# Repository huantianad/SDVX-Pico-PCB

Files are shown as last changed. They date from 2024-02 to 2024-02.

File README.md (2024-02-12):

# SDVX Pico PCB

A quick and dirty custom PCB I designed for use with a Raspberry Pi Pico. Wired up for 7 buttons and 2 knobs, and option WS2812B strip. Connectors are JST-XH, with button LEDs running off of 5V. Because of that, I used 2N2222 BJTs to toggle the LEDs off of the 3.3V on the pico.

Indended for use with a slightly tweaked [Pico-Game-Controller](https://github.com/huantianad/Pico-Game-Controller). You may have to edit the encoder PPR and encoder inversion settings.

Encoders are wired for Data, Data, +5V, GND; buttons are wired for Switch GPIO, LED GND, LED 5V, Switch GND.

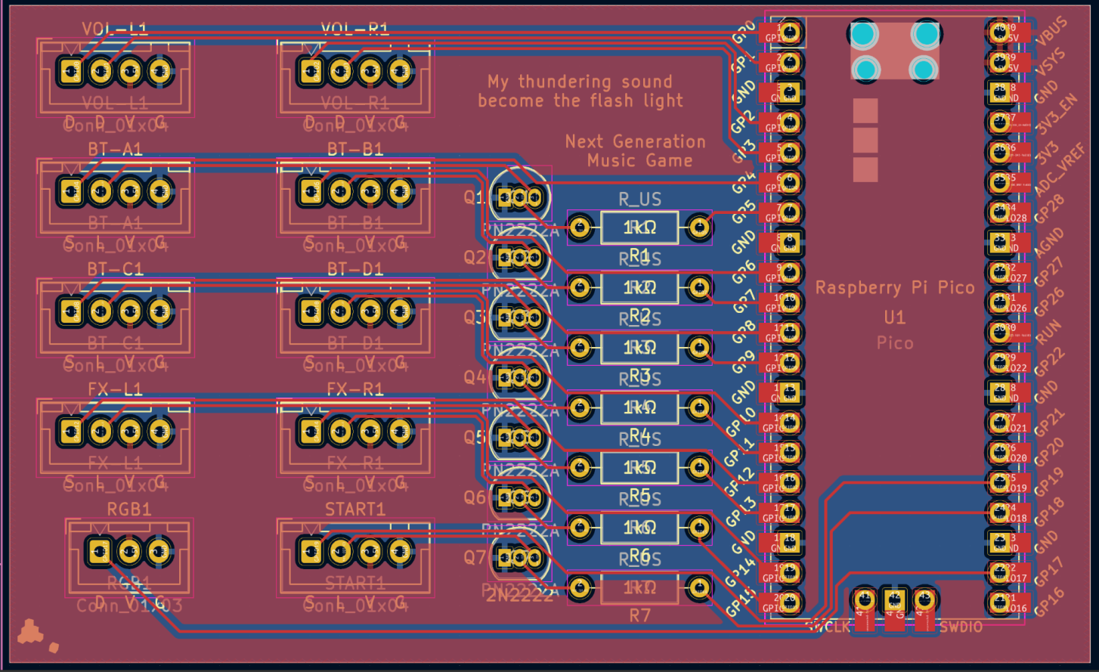
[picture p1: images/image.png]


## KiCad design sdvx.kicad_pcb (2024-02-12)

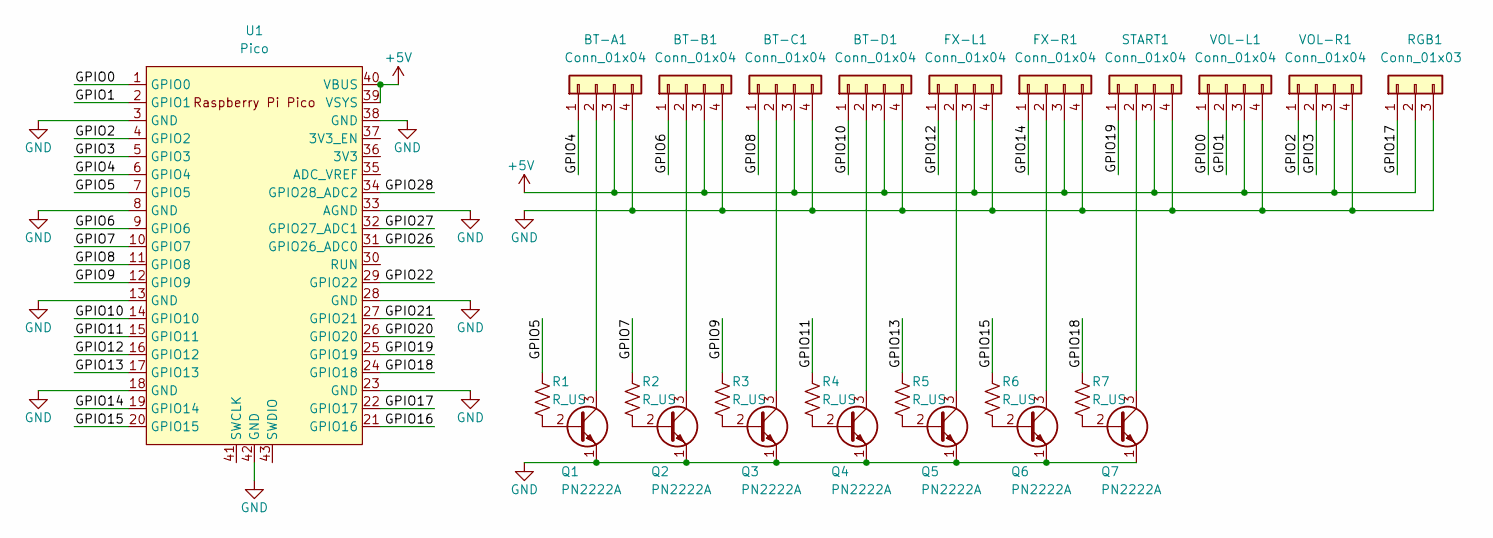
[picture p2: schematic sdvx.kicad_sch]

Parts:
BT-A1: Conn_01x04; JST_XH_B4B-XH-A_1x04_P2.50mm_Vertical
BT-B1: Conn_01x04; JST_XH_B4B-XH-A_1x04_P2.50mm_Vertical
BT-C1: Conn_01x04; JST_XH_B4B-XH-A_1x04_P2.50mm_Vertical
BT-D1: Conn_01x04; JST_XH_B4B-XH-A_1x04_P2.50mm_Vertical
FX-L1: Conn_01x04; JST_XH_B4B-XH-A_1x04_P2.50mm_Vertical
FX-R1: Conn_01x04; JST_XH_B4B-XH-A_1x04_P2.50mm_Vertical
Q1, Q2, Q3, Q4, Q5, Q6, Q7: PN2222A; TO-92_Inline
R1, R2, R3, R4, R5, R6, R7: R_US; R_Axial_DIN0207_L6.3mm_D2.5mm_P10.16mm_Horizontal
RGB1: Conn_01x03; JST_XH_B3B-XH-A_1x03_P2.50mm_Vertical
START1: Conn_01x04; JST_XH_B4B-XH-A_1x04_P2.50mm_Vertical
U1: Pico; RPi_Pico_SMD_TH
VOL-L1: Conn_01x04; JST_XH_B4B-XH-A_1x04_P2.50mm_Vertical
VOL-R1: Conn_01x04; JST_XH_B4B-XH-A_1x04_P2.50mm_Vertical

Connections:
+5V: BT-A1.3, BT-B1.3, BT-C1.3, BT-D1.3, FX-L1.3, FX-R1.3, RGB1.2, START1.3, U1.39 (VSYS), U1.40 (VBUS), VOL-L1.3, VOL-R1.3
/GPIO0: U1.1 (GPIO0), VOL-L1.1
/GPIO1: U1.2 (GPIO1), VOL-L1.2
/GPIO2: U1.4 (GPIO2), VOL-R1.1
/GPIO3: U1.5 (GPIO3), VOL-R1.2
/GPIO4: BT-A1.1, U1.6 (GPIO4)
/GPIO5: R1.1, U1.7 (GPIO5)
/GPIO6: BT-B1.1, U1.9 (GPIO6)
/GPIO7: R2.1, U1.10 (GPIO7)
/GPIO8: BT-C1.1, U1.11 (GPIO8)
/GPIO9: R3.1, U1.12 (GPIO9)
/GPIO10: BT-D1.1, U1.14 (GPIO10)
/GPIO11: R4.1, U1.15 (GPIO11)
/GPIO12: FX-L1.1, U1.16 (GPIO12)
/GPIO13: R5.1, U1.17 (GPIO13)
/GPIO14: FX-R1.1, U1.19 (GPIO14)
/GPIO15: R6.1, U1.20 (GPIO15)
/GPIO16: U1.21 (GPIO16)
/GPIO17: RGB1.1, U1.22 (GPIO17)
/GPIO18: R7.1, U1.24 (GPIO18)
/GPIO19: START1.1, U1.25 (GPIO19)
/GPIO20: U1.26 (GPIO20)
/GPIO21: U1.27 (GPIO21)
/GPIO22: U1.29 (GPIO22)
/GPIO26: U1.31 (GPIO26_ADC0)
/GPIO27: U1.32 (GPIO27_ADC1)
/GPIO28: U1.34 (GPIO28_ADC2)
GND: BT-A1.4, BT-B1.4, BT-C1.4, BT-D1.4, FX-L1.4, FX-R1.4, Q1.1 (E), Q2.1 (E), Q3.1 (E), Q4.1 (E), Q5.1 (E), Q6.1 (E), Q7.1 (E), RGB1.3, START1.4, U1.3 (GND), U1.8 (GND), U1.13 (GND), U1.18 (GND), U1.23 (GND), U1.28 (GND), U1.33 (AGND), U1.38 (GND), U1.42 (GND), VOL-L1.4, VOL-R1.4
unnamed: BT-A1.2, Q1.3 (C)
unnamed: BT-B1.2, Q2.3 (C)
unnamed: BT-C1.2, Q3.3 (C)
unnamed: BT-D1.2, Q4.3 (C)
unnamed: FX-L1.2, Q5.3 (C)
unnamed: FX-R1.2, Q6.3 (C)
unnamed: Q1.2 (B), R1.2
unnamed: Q2.2 (B), R2.2
unnamed: Q3.2 (B), R3.2
unnamed: Q4.2 (B), R4.2
unnamed: Q5.2 (B), R5.2
unnamed: Q6.2 (B), R6.2
unnamed: Q7.2 (B), R7.2
unnamed: Q7.3 (C), START1.2

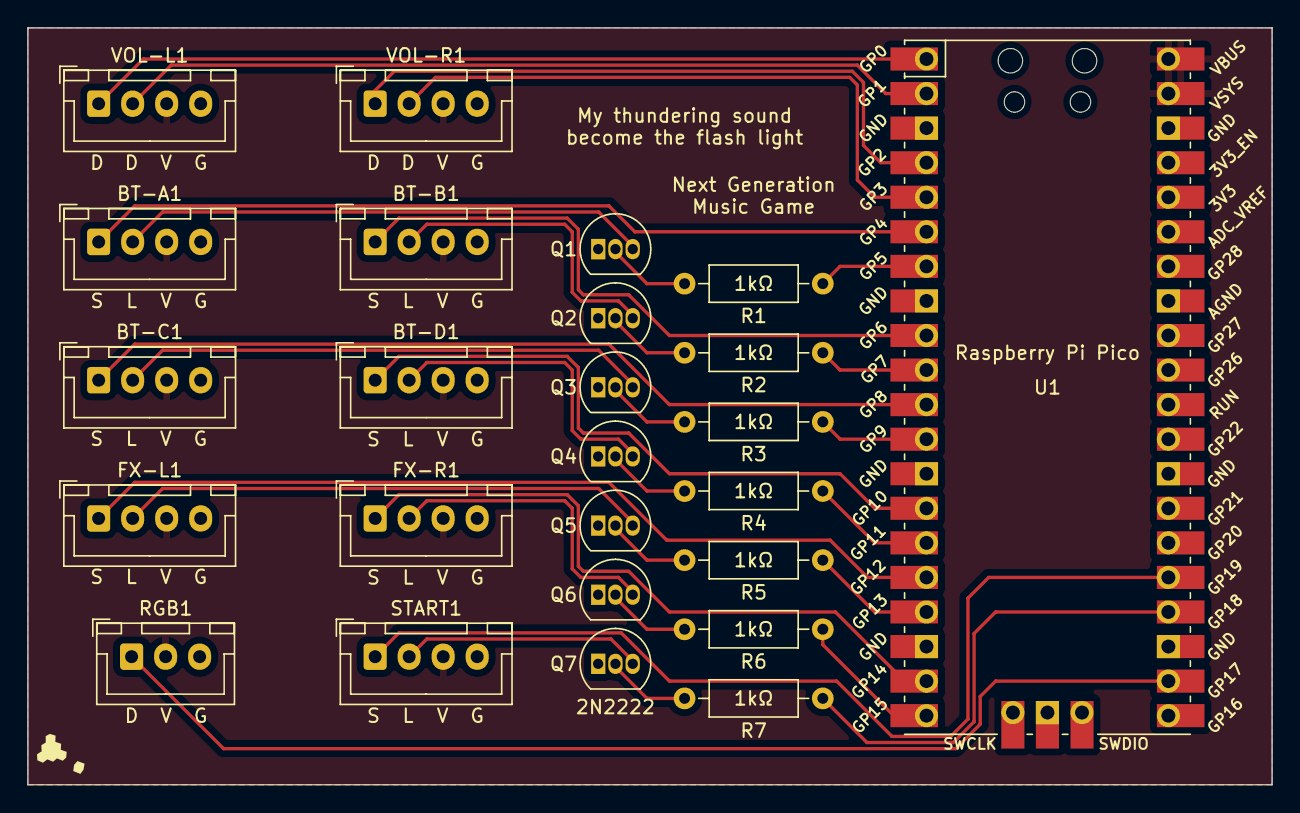
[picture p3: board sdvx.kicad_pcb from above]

Board: 2 copper layers, 91.4 x 55.6 mm, 26 parts (0 on the bottom side), 35 nets.

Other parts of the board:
LOGO: LOGO
